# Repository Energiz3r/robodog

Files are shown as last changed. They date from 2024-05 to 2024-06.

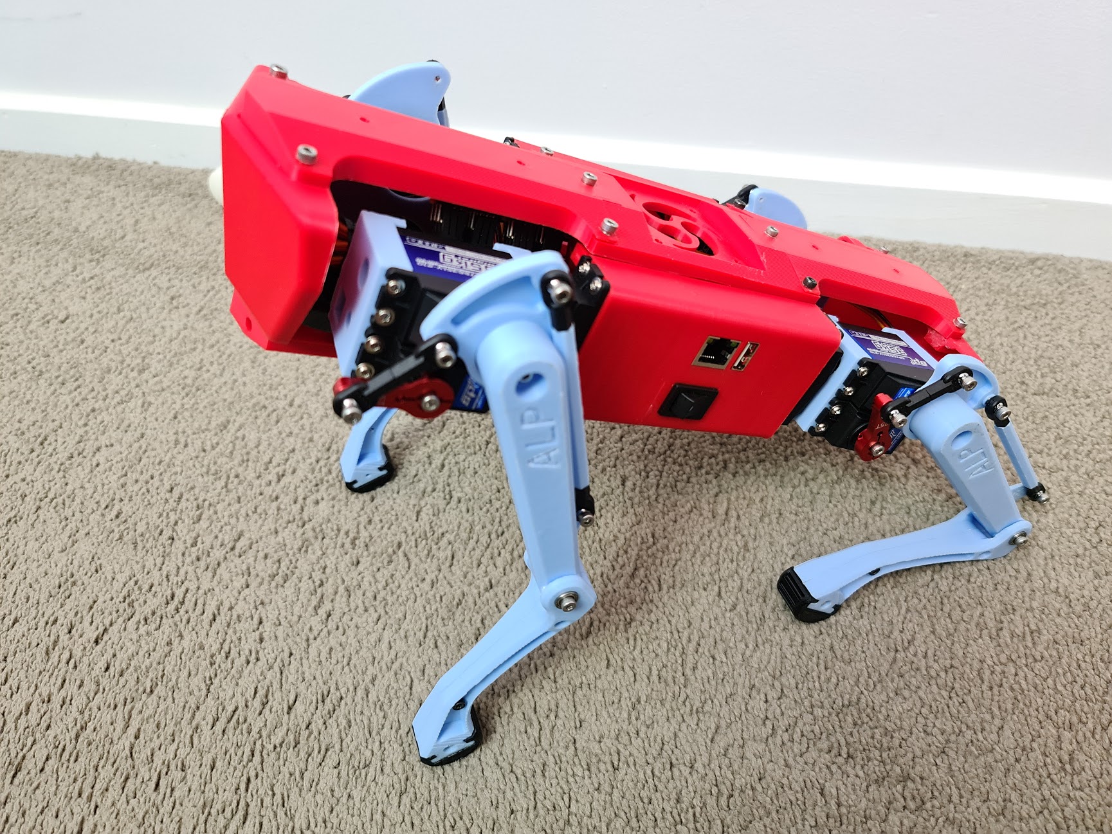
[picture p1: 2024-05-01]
img/robodog.jpg

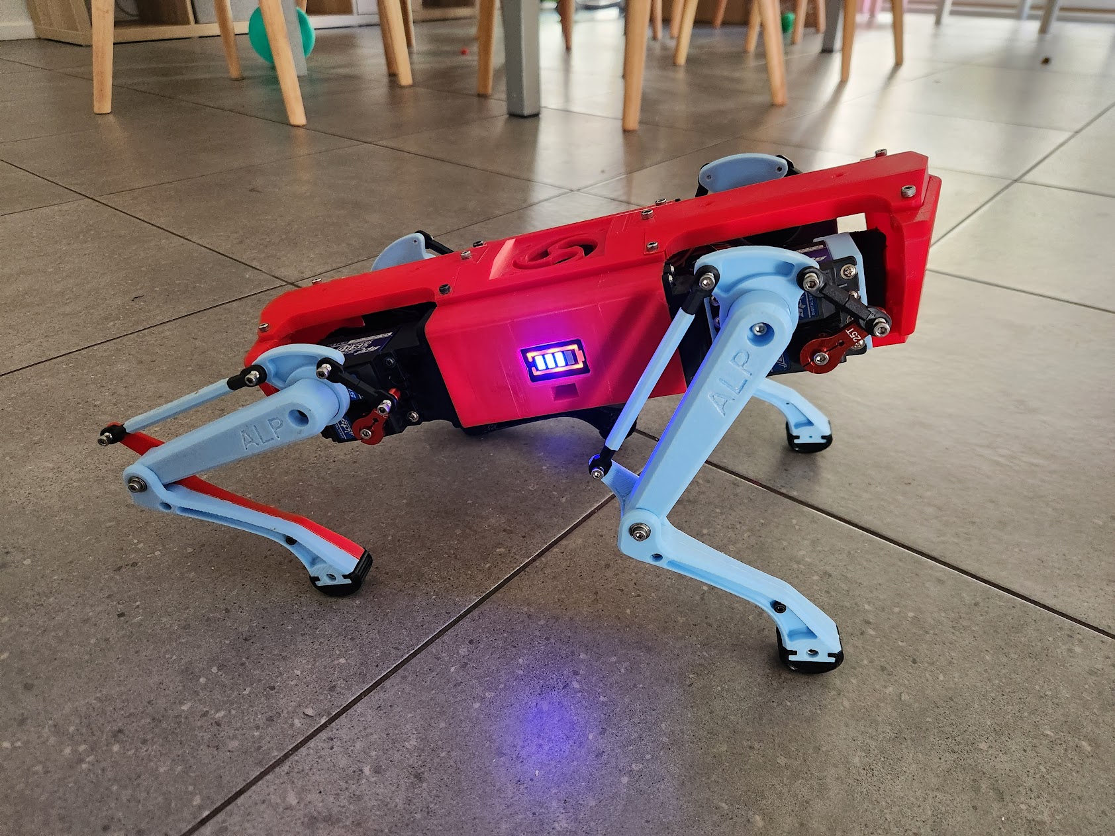
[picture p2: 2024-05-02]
img/robodog2.jpg

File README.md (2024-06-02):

# robodog - the noob friendly quadruped robot

*Click thumbnail to play video (YouTube):*

youtube video (https://www.youtube.com/watch?v=46twC60OhOA)

### Credits: 

Some design and code based on work by these guys:

- "Baris ALP" - https://grabcad.com/library/diy-quadruped-robot-1
- "[Jack Demeter](https://github.com/JackDemeter)" https://grabcad.com/library/quadruped-robot-w-code-1

## Overview

I attempted to learn ROS starting from zero experience with robotic development and found it to be way more complicated than I was prepared to deal with learning at the time. If you wish to operate a robot like this *properly*, you should really a) build a robot with closed-loop motor control, ie. not using R/C servos, and b) learn to create a physic simulation (for ROS, that would be in Gazebo, as far I could tell) and have ROS operate your robot's motors based on actual physical simulation and accelerometer data.

In layman's terms, the code in this repo lets you control the robot and walk it around, but it's really just playing a fixed animation of the legs rather than 'knowing' how to walk.

I wrote my code in NodeJS. I had extreme difficulty and ultimately failed getting other projects to run on the OrangePi Zero LTS due to python dependencies and differences between the distros which can be a nightmare at the best of times. Not having a real Rpi handy, nor being prepared to buy one for the sake of Python, nor wanting to change the robot design to accommodate it, I went with NodeJS. As a front-end dev this was natural to me. Use of Node reduces the only real compatibility challenges for other people using this repo to surfacing an i2c interface to talk to the PWM controller.

## Assembly

This is the easy part! I'll add physical build instructions soon.

## Electronics Required

- OrangePi Zero LTS, or other Rpi / OrangePi board (untested)
- PCA9685 16-channel 12-bit PWM driver (Adafruit)
- 10x Servos
  - I used `SPT5535LV-210` Servos from Aliexpress. They're digital metal-gear units with 200&deg; rotation and a pulse width of 500&micro;s - 2500&micro;s.
  - There were many options to choose from; I selected both the 35kg rating (higher torque gearing reduces rotation speed) and included the optional red anodized aluminium arm, which I used.
  - Be aware if you stall these servos and have a powerful enough supply of current, they will burn very quickly. Make sure your robot is assembled and the servos properly positioned before you attach the legs.

Instead of using a regulator, I opted to power my servos directly from the battery, which is 2x 18650 cells in series for a nominal 7.4V. The servos I used are fine with this voltage and I imagine most will be as it's standard practice to power servos from a 2S LiPo in R/C cars. The robot runs for at least an hour on a single charge, so they seem to be plenty.

## Bill of Materials

Will update with complete list once the project is mature.

<details>
(draft)

- Orange Pi Zero
- Rocker switch - local electronics store
- 12x spt5435LV
- 2x dc-dc SZBK07 (* I did not use these. heavy!)
- 2x 18650 (I used Sony VTC6)
- battery indicator - choose to suit your battery configuration and chemistry
- 50X50X10mm fan
- 16x 5mm R/C tie rod end (HPI)
- 8x 603ZZ 3x9x5mm bearings
- You would need a 5v regulator to power the Orange Pi
- Assorted length M3 bolts and nyloc nuts

</details>

## Installation

Check that i2c is enabled for your board. For OrangePi and possibly other Armbian boards, run `sudo armbian-config`, select `System (System and security settings)` then `Hardware (Toggle hardware configuration)`, and mark i2c0 to enable it. Select save and you'll be prompted to reboot your OrangePi.

- Clone the repo
- run `npm install`
- edit `config.js`
  - set the pin assignments for your Servos to the PCA9685 PWM controller
  - set `calibrate: true` so your servos are in centre position to attach the legs
  - under pca9685, the `i2cDevice` value corresponds to your device in linux, eg. for `/dev/i2c0` or `/dev/i2c-0` you would set this to `0`. (use `ls -l /dev/i2c*` to check. If not found, you need to enable i2c for your board)  
- run `node robot.js` or use `npm run start`
- access the page at `http://<device IP>:3000` and use the buttons or WASD to control the robot

**Note about hardware dependencies:**

Hardware-specific dependencies are set as optional in `package.json`:
```json
{ "optionalDependencies": {
    "i2c-bus": "^5.2.3",
    "pca9685": "^5.0.0"
}}
```
You can therefore do the install on a desktop OS and run the software, but i2c and the PCA9685 will be simulated and do nothing - you will see a message in console to confirm whether or not the hardware dependencies are OK or being simulated. All of the kinematic calculations are still executed so this was handy for development.

## Gait Visualisation

run `node visualise.js` to see the gait visualised on a 3D plot

Edit `visualise.js` to modify which gait file is visualised (default `gaits/basic.js`)

## Development Status

Overall status

See related Git project for planned and in-progress features: https://github.com/users/Energiz3r/projects/2

I'm absolutely useless when it comes to 3D modelling. The parts I've modified were done so in [123D Design](https://autodesk-123d-design.en.lo4d.com/windows), a discontinued piece of *very* basic software from Autodesk. If you want proper design files you'll need to make / convert them yourself. Contributions of all kind are welcome, but conversion of the 3D files to proper CAD format especially so.

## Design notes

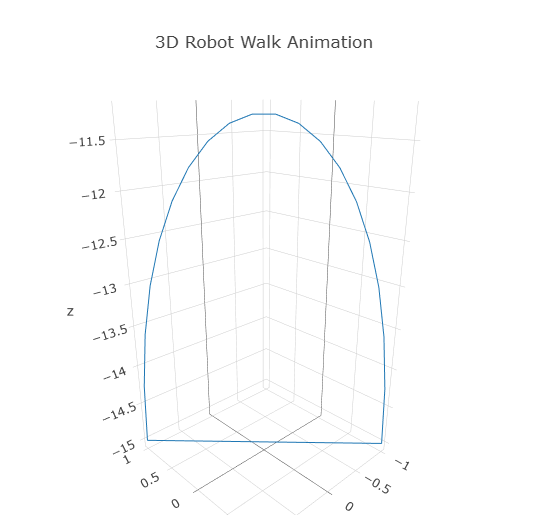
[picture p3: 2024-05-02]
img/plot.png

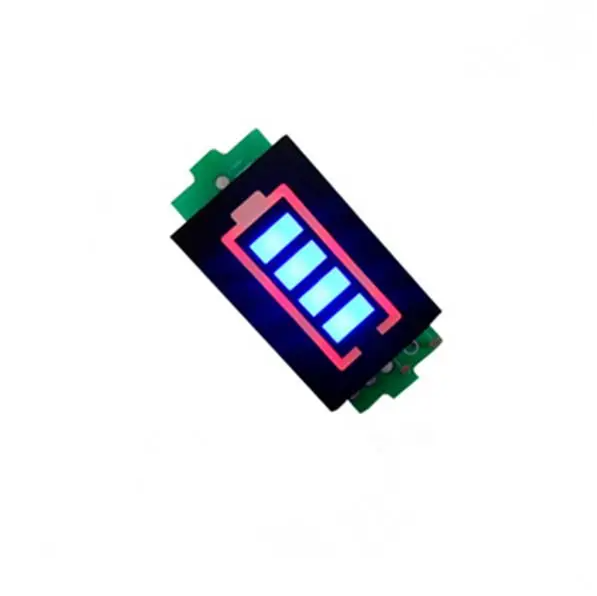
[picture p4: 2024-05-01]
img/battery-gauge2.png

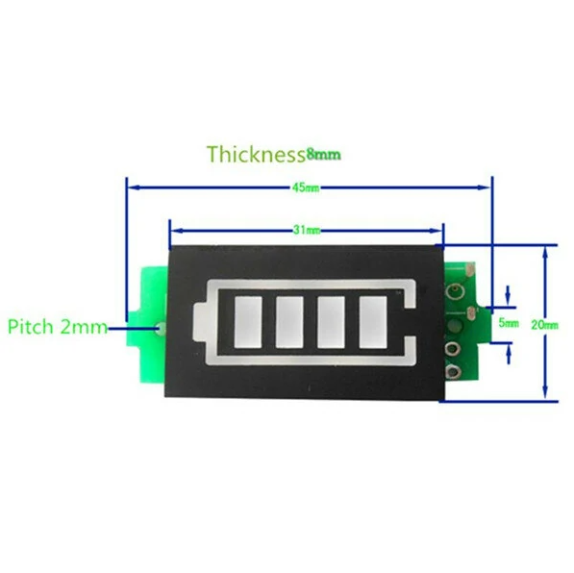
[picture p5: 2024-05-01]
img/battery-gauge.png

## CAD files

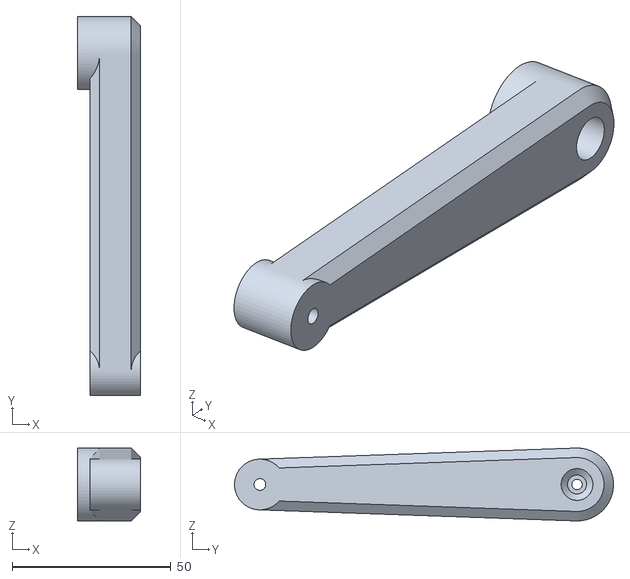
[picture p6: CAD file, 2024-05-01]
3D/femur.stl
20.0 x 119.5 x 23.0

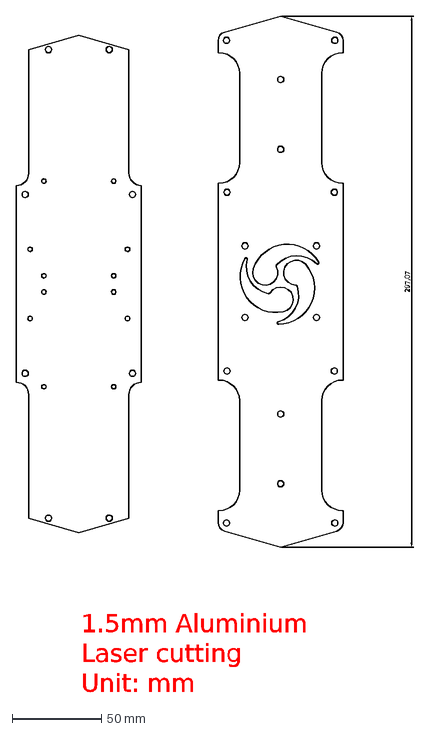
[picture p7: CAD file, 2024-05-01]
3D/Lasercut_dxf_/Lasercut parts.dxf
1.5mm Aluminium Laser cutting Unit: mm
297,07

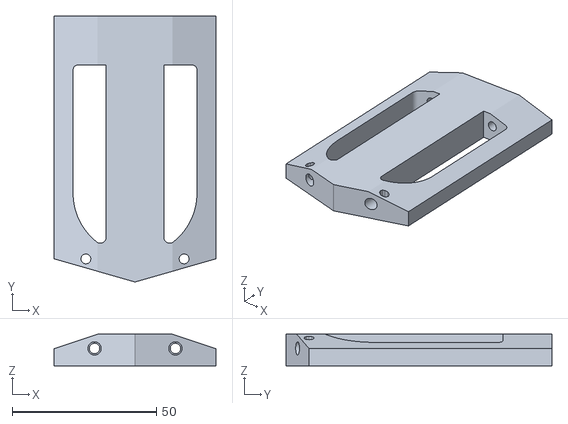
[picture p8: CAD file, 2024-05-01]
3D/bot-plate-B-thic.stl
56.0 x 92.1 x 10.9

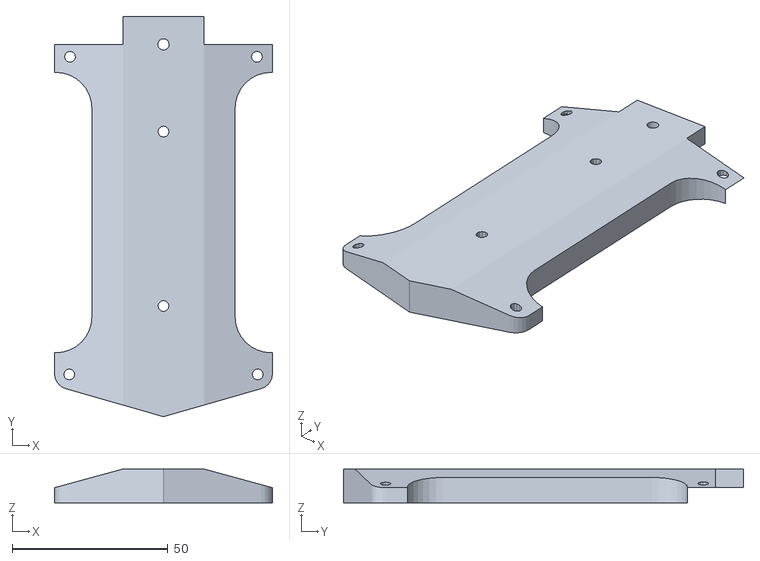
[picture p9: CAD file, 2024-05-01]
3D/top-plate-B-thic.stl
70.0 x 128.5 x 10.9

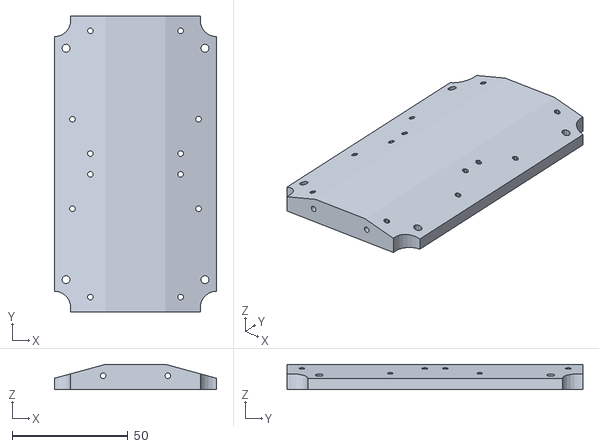
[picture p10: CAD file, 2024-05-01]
3D/bot-plate-A-thic.stl
70.0 x 127.8 x 10.9

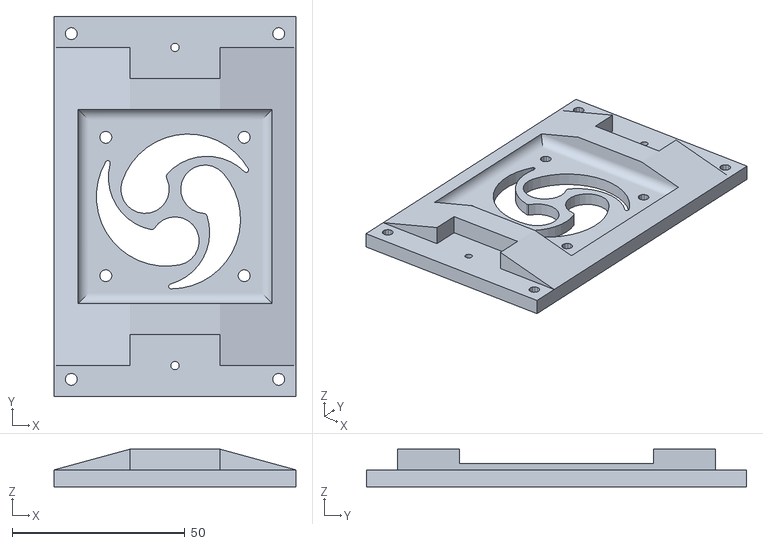
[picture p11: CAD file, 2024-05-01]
3D/top-plate-A-thic.stl
70.0 x 110.0 x 10.9

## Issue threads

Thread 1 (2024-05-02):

refine basic gait

Energiz3r, 2024-05-02:
Robodog doesn't walk very well. I think timing of the leg motion relative to each other is off, as the motion itself looks fine. The robot is quite heavy which seems to amplify the issue

Energiz3r, 2024-06-02:
Basic gait is greatly improved but still has some balance issues, eg. as it lifts opposite legs, it will rock back onto the rear leg rather than balancing. Without an actual IMU, fixing this seems like it's down to messing with the geometry / calibration of the legs

For now will resolve issue as this entire codebase isn't really 'proper' way of doing things anyway and there's better uses of time

Closed 2024-06-02.

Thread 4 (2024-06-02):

create Servo Controller in NodeJS

Energiz3r, 2024-06-02:

Energiz3r, 2024-06-02:
As the 16x channel servo / PWM controller uses i2c for communication, this was a fairly simple implementation using a lib I found on npmjs. I created a servo controller class to implement an initializer and a `setAngle` function which maps angle to pulse widths to write to the channels of the controller.

This quickly crashed the OrangePi with memory overflow, and I realised the i2c driver is quite slow to resolve a write. Promises are returned from a write request, so I solved this by having the servo controller class ignore additional setAngle requests for that channel if the previous has not yet completed. This works well and there does not appear to be any side effect - I was concerned that this meant the driver was slower than my update rate of ~20ms but this does not appear to be the case as the responsiveness of the robot is visibly increased changing the update rate to as fast as 5ms. As it's working, and I don't want to edit the driver, I won't investigate further

Closed 2024-06-02.

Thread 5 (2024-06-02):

WebUI for WASD / Touch control

Energiz3r, 2024-06-02:

Energiz3r, 2024-06-02:
I've built a basic webUI which is hosted by an Express server. A worker thread is spawned to execute the actual robot controller to prevent blocking of the server calls, as the robot's main thread / loop is a blocking process (NodeJS does not have a non-blocking `sleep` or `wait` function).

Websocket is used to send updates to the server, and worker post messages are used to pass these events to the robot thread

For now the UI is a simple HTML / css page with some buttons on it for touch screen and keyboard inputs. A separate ticket exists to add controller input support to the page

In theory any client with websocket support should be able to control the robot, but for automated input a different method of control may be needed

Closed 2024-06-02.

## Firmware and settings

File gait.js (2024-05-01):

var {Bezier} = require("bezier-js");
var linspace = require("linspace");
var config = require("./config");

const formatMemoryUsage = (data) => `${Math.round(data / 1024 / 1024 * 100) / 100} MB`;

class Gait {
    constructor(servoController, motors) {
        this.motors = motors
        this.servoController = servoController;
        this.upper_leg_length = 10;
        this.lower_leg_length = 10.5;
        this.writingServos = []
    }

    setAngle(motor_id, degrees) {
        if (!this.writingServos.includes(motor_id)) {
            this.writingServos.push(motor_id)
            const callback = () => {
                this.writingServos = this.writingServos.filter(id => id !== motor_id)
            }
            const servo = this.servoController.servo.find(servo => servo.channel === motor_id)
            servo.setAngle(degrees, callback);
        }
        // else {
        //     console.log("Tried to overwrite a servo")
        // }
    }

    radToDegree(rad) {
        return (rad * 180) / Math.PI;
    }

    calibrate() {
        this.setAngle(this.motors.FR_SHOULDER, 60);
        this.setAngle(this.motors.FR_ELBOW, 90);
        this.setAngle(this.motors.FR_HIP, 90);
        this.setAngle(this.motors.FL_SHOULDER, 120);
        this.setAngle(this.motors.FL_ELBOW, 90);
        this.setAngle(this.motors.FL_HIP, 90);
        this.setAngle(this.motors.BR_SHOULDER, 60);
        this.setAngle(this.motors.BR_ELBOW, 90);
        this.setAngle(this.motors.BR_HIP, 90); // unused
        this.setAngle(this.motors.BL_SHOULDER, 120);
        this.setAngle(this.motors.BL_ELBOW, 90);
        this.setAngle(this.motors.BL_HIP, 90); // unused
    }

    inversePositioning(shoulder, elbow, x, y, right, z = 0, hip = null) {
        const L = 2;
        const y_prime = -Math.sqrt((z + L) ** 2 + y ** 2);
        const thetaz =
            Math.atan2(z + L, Math.abs(y)) - Math.atan2(L, Math.abs(y_prime));

        const elbow_offset = 20;
        const shoulder_offset = 10;
        const a1 = this.upper_leg_length;
        const a2 = this.lower_leg_length;

        let c2 = (x ** 2 + y_prime ** 2 - a1 ** 2 - a2 ** 2) / (2 * a1 * a2);
        let s2 = Math.sqrt(1 - c2 ** 2);
        let theta2 = Math.atan2(s2, c2);
        c2 = Math.cos(theta2);
        s2 = Math.sin(theta2);

        const c1 =
            (x * (a1 + a2 * c2) + y_prime * (a2 * s2)) / (x ** 2 + y_prime ** 2);
        const s1 =
            (y_prime * (a1 + a2 * c2) - x * (a2 * s2)) / (x ** 2 + y_prime ** 2);
        let theta1 = Math.atan2(s1, c1);
        // generate positions with respect to robot motors
        let theta_shoulder = -theta1;
        let theta_elbow = theta_shoulder - theta2;
        let theta_hip = 0;
        if (right) {
            theta_shoulder = 180 - this.radToDegree(theta_shoulder) + shoulder_offset;
            theta_elbow = 130 - this.radToDegree(theta_elbow) + elbow_offset;
            if (hip) {
                theta_hip = 90 - this.radToDegree(thetaz);
            }
        } else {
            theta_shoulder = this.radToDegree(theta_shoulder) - shoulder_offset;
            theta_elbow = 50 + this.radToDegree(theta_elbow) - elbow_offset;
            if (hip) {
                theta_hip = 90 + this.radToDegree(thetaz);
            }
        }

        //if (shoulder === 0) console.log("shoulder:",theta_shoulder,"elbow:",theta_elbow, "hip:", theta_hip);
        this.setAngle(shoulder, theta_shoulder);
        this.setAngle(elbow, theta_elbow);
        if (hip) {
            this.setAngle(hip, theta_hip);
        }
    }

    leg_position(self, leg_id, x, y, z = 0) {
        if (leg_id === 'FL')
            this.inversePositioning(this.motors.FL_SHOULDER, this.motors.FL_ELBOW, x, y, false, z, this.motors.FL_HIP)
        if (leg_id === 'FR')
            this.inversePositioning(this.motors.FR_SHOULDER, this.motors.FR_ELBOW, x, y, true, z, this.motors.FR_HIP)
        if (leg_id === 'BL')
            this.inversePositioning(this.motors.BL_SHOULDER, this.motors.BL_ELBOW, x, y, false)
        if (leg_id === 'BR')
            this.inversePositioning(this.motors.BR_SHOULDER, this.motors.BR_ELBOW, x, y, true)
    }

    move(controller) {
        const s_vals = linspace(0.0, 1.0, 20);

        const step_nodes = [
            {x: -1.0, y: -1.0, z: -15.0},
            {x: -1.0, y: -1.0, z: -10.0},
            {x: 1.0, y: 1.0, z: -10.0},
            {x: 1.0, y: 1.0, z: -15.0}
        ]
        const stepCurve = new Bezier(step_nodes);
        const step = s_vals.map(t => stepCurve.get(t));

        const slide_nodes = [
            {x: 1.0, y: 1.0, z: -15.0},
            {x: -1.0, y: -1.0, z: -15.0}
        ];
        const slideCurve = new Bezier(slide_nodes);
        const slide = s_vals.map(t => slideCurve.get(t));

        const motion = step.concat(slide)

        let close = false;
        let momentum = [0, 0, 1, 0];
        let index = 0;

        let lastLoopTime = process.hrtime();
        const loop = () => {
            if (close) {
                console.log("Loop was terminated.")
                process.exit();
            }

            const difference = process.hrtime(lastLoopTime)[1];
            if (difference > 500 * 1000) { // 500 microseconds
                lastLoopTime = process.hrtime();
            } else {
                setTimeout(loop, 0)
                return
            }

            momentum = controller(momentum);
            const trajectory = motion.map(point => ({
                x: point.x * momentum[0],
                y: point.y * momentum[1],
                z: point.z * momentum[2]
            }));

            if (momentum[3]) {
                console.log("momentum[3] was truthy!")
                close = true;
            }

            const x = trajectory.map(point => point.x);
            const y = trajectory.map(point => point.z); // swapped z and y to be same as python
            const z = trajectory.map(point => point.y);

            const i1 = index % 40;
            const i2 = (index + 20) % 40;

            this.inversePositioning(this.motors.FR_SHOULDER, this.motors.FR_ELBOW, x[i1], y[i1] - 1, true, z[i1], this.motors.FR_HIP);
            this.inversePositioning(this.motors.BR_SHOULDER, this.motors.BR_ELBOW, x[i2], y[i2] + 2, true);
            this.inversePositioning(this.motors.FL_SHOULDER, this.motors.FL_ELBOW, x[i2], y[i2] - 1, false, -z[i2], this.motors.FL_HIP);
            this.inversePositioning(this.motors.BL_SHOULDER, this.motors.BL_ELBOW, x[i1], y[i1] + 2, false);
            index++;

            setTimeout(loop, config.speed)
        }

        setInterval(() => {
            const memoryData = process.memoryUsage();
            console.log(`Heap total: ${formatMemoryUsage(memoryData.heapTotal)}`, close ? "NOT running" : "running");
        }, 1000)

        console.log("Running robot...")
        loop()
    }
}

module.exports = Gait;

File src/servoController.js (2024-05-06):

const chalk = require('chalk');
const config = require('../config');
const utils = require('./utils');

let i2cBus;
let Pca9685Driver;
let pca9685ODevice;

// load dummy drivers if modules aren't installed
try {
    i2cBus = require('i2c-bus');
    Pca9685Driver = require('pca9685').Pca9685Driver;
    console.log(chalk.green('Hardware libraries OK!'));
} catch (error) {
    console.log(chalk.yellowBright('Hardware libraries not available! Simulating servo output.'));
    i2cBus = require('./dummyHardware').dummyI2C
    Pca9685Driver = require('./dummyHardware').dummyPCA
}

const pca9685Options = {
    i2c: i2cBus.openSync(config.pca9685.i2cDevice),
    address: config.pca9685.address,
    frequency: config.pca9685.frequency,
    debug: config.pca9685.debug
};

class Servo {

    channel = 0;
    offset = 0;
    isReady = false;
    isBusy = false;

    constructor(motor) {
        this.channel = motor.channel;
        this.offset = motor.offset;
    }

    init() {
        pca9685ODevice.setPulseRange(this.channel, 500, 2500)
        this.isReady = true;
    }

    setAngle(degrees) {
        // writing to the servo fast repeatedly without waiting until the callback is resolved causes memory overflow
        if (!this.isBusy) {
            this.isBusy = true;
            let newDegrees = degrees + this.offset
            if (newDegrees < 0) newDegrees = 0;
            if (newDegrees > 360) newDegrees = 360;
            const pulseLength = utils.mapNumber(newDegrees, 0, 180, 500, 2500)
            pca9685ODevice.setPulseLength(this.channel, pulseLength, 2500, () => this.isBusy = false)
        }
    }
}

class ServoController {
    servos = [];
    isReady = false;
    isPowerOn = true;

    constructor() {
        this.servos = Object.keys(config.motors).map((key) => {
            return new Servo(config.motors[key])
        });
        this.initialize().then(() => {
            this.servos.forEach(servo => servo.init())
            this.isReady = true;
        }).catch(err => {
            console.error("Error initializing PCA9685!", err);
            process.exit(-1);
        })
    }

    setAngle(channel, degrees){
        if (this.isPowerOn) {
            const servo = this.servos.find(servo => servo.channel === channel)
            servo.setAngle(degrees);
        }
    }

    setPower(powerOn) {
        if (powerOn) {
            this.isPowerOn = true
            this.servos.forEach(servo => pca9685ODevice.channelOn(servo.channel))
        } else {
            this.isPowerOn = false
            pca9685ODevice.allChannelsOff()
        }
    }

    initialize() {
        return new Promise((resolve, reject) => {
            pca9685ODevice = new Pca9685Driver(pca9685Options, (err) => {
                if (err) {
                    reject(err);
                } else {
                    resolve();
                }
            });
        });
    }
}

module.exports = ServoController;

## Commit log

2024-05-01 test servo
2024-05-01 i2c seeming to work
2024-05-01 servo test
2024-05-01 local copy of PCA driver
2024-05-01 motors moved to config
2024-05-01 restructure & readme
    [Lasercut parts.dxf, bot-plate-A-thic.stl, bot-plate-B-thic.stl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]
2024-05-02 fix buttons on touch displays
2024-05-06 add motor offset
